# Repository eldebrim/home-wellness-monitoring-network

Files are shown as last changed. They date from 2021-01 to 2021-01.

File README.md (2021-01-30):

# Home Wellness Monitoring Network
 
## Overview
Develop a network of identical devices that keep track of positive activities through a usable interface.
Examples of activities to be tracked include taking medication, performing
exercise, and eating healthy food. The activities will be viewable through an online portal.
The portal will allow users to create custom activities so they can be tracked.

Each directory in this repo is used to store documentation for different blocks, along with the
files necessary to replicate them. A PDF setup guide is also included to explain how each device
is setup after it's manufactured.

Link to the team's Google site: https://sites.google.com/oregonstate.edu/ece44x201928/home-wellness-monitoring

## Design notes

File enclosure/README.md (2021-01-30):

# Enclosure
This directory includes the STL files used for the enclosure and lid. If you're an OSU student,
you can make use of the valley library (https://guides.library.oregonstate.edu/3Dprinting) to upload the
STL files and print the enclosure in 1-3 days.

Another alternative for 3D printing if you're not an OSU student is Print a Thing (https://printathing.com/).

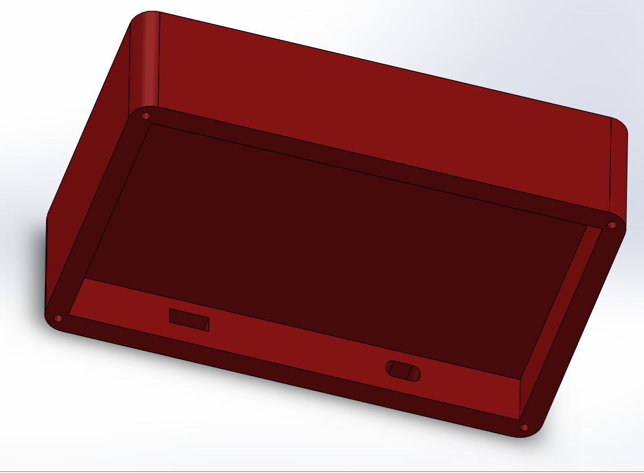
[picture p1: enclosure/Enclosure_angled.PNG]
Enclosure angled Enclosure Angled

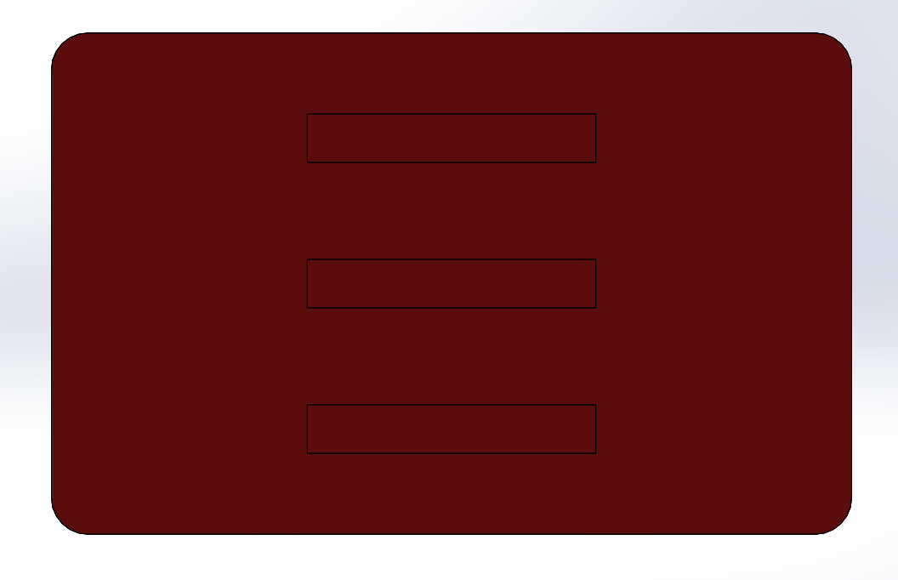
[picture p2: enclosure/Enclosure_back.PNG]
Enclosure back Enclosure Back

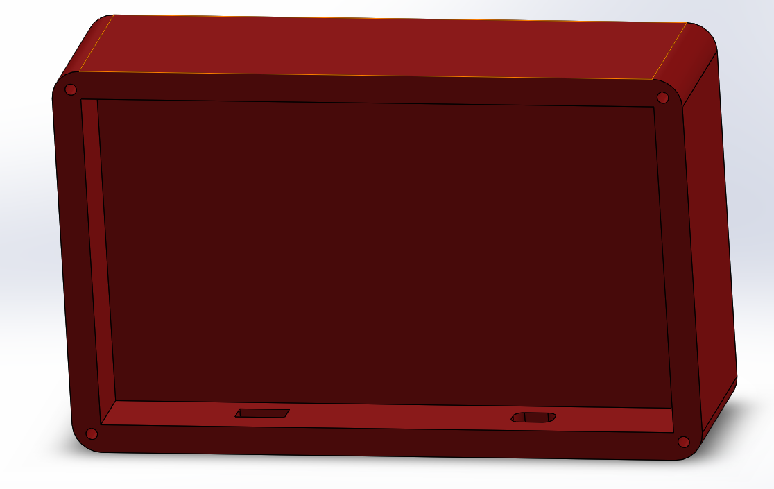
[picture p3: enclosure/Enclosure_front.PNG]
Enclosure front Enclosure Front

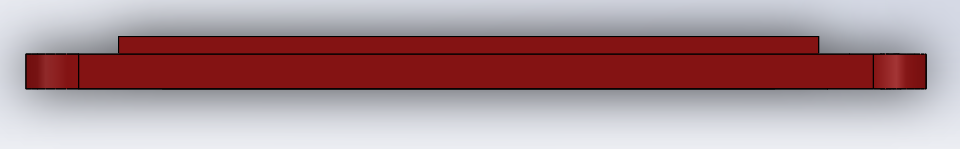
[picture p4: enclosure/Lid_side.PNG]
Lid side Lid Side

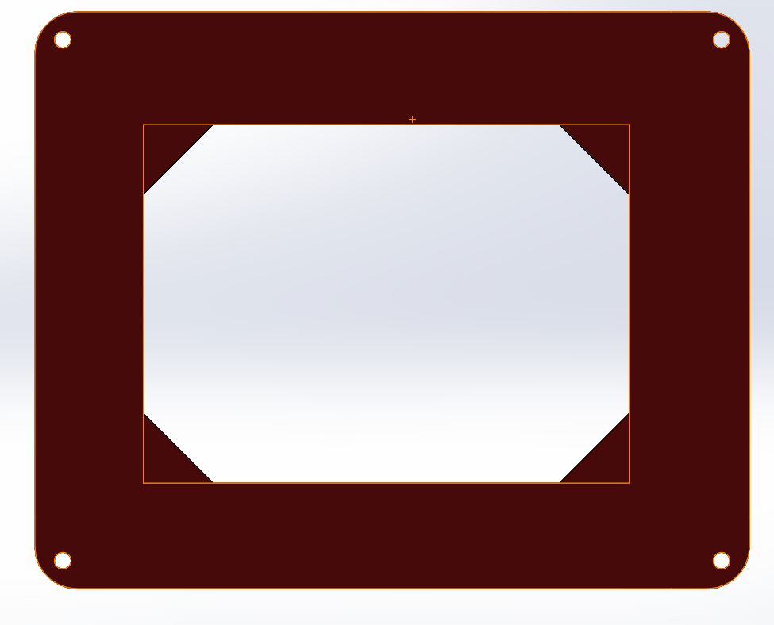
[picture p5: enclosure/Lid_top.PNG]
Lid top Lid Top


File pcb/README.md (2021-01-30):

# PCB
## Building PCB:
1. Go to OSH Park website (https://oshpark.com/).
2. Upload 'Board_1' from PCB Repository to the oshpark website by clicking the 'Browse For Files'.
3. Wait for OSH park to process files.
4. in 'Description' section enter 'Home Wellness Monitoring Network IOT Device.'
5. In 'Email' section enter your email.
6. click 'Continue' to go to 'Verify your design section'.
7. Click on 'Order' to place go to checkout section.
8. Enter your shipping and billing order to place an order for the PCB.

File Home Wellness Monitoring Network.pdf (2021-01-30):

User Guide

# Home Wellness Monitoring Network

Version 1.0

Introduction | 2
Monitoring Device Set-Up | 2
Connecting to Wi-Fi | 2
Wi-Fi troubleshooting | 3
Further Set-Up | 3
Web Profile Set-Up | 3

# Introduction

Welcome to your new Home Wellness Monitoring Network. We hope to help you with your wellness needs. Whether you want to remember to take your vitamins or brush your teeth, we hope this device can help you.

# Monitoring Device Set-Up

Out of the box, your Monitoring Device should have pre-installed magnets on the back, shown in Figure 1. After mounting it using these magnets, the Monitoring Device should be ready to plug into the wall. Plug it in and make sure the switch on the power cord is ON.

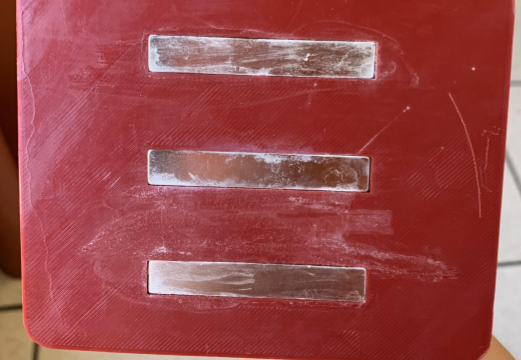
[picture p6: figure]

Figure 1. Three mounting magnets on backside of Monitoring Device

## Connecting to Wi-Fi

After turning on the Monitoring Device. You should be prompted to search for an access point for wireless connection. Simply select your wireless network from the list and enter the password if required.

Wi-Fi troubleshooting
If your wireless network is not listed, ensure your wireless router is in close proximity to the Monitoring Device.

## Further Set-Up

After connecting to a wireless network, your device should take a few moments to update to any settings that may be connected to that device’s identification number.

# Web Profile Set-Up

Proper utilization of the Home Wellness Monitoring Network requires set-up of the Web Profile.

1. Go to Website on a computer or smart device.
2. Create a secure account if you do not have one already
3. Add a device using the identification number which can be found on the backside of the device, as well as on the inside cover of the box the device originally was packaged in.
4. It is recommended that you name your device to ensure ease of use.
5. Add tasks under the device’s profile, as seen in Figure 2. Your device should automatically update, however, if the Monitoring Device does not self-refresh, reset the device by switching it off for five seconds and then switching it on again.

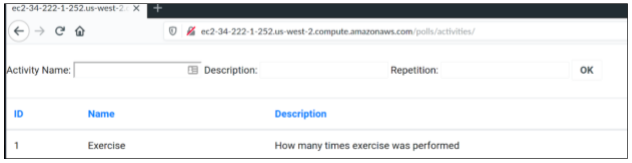
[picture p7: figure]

Figure 2. Adding a task to your device

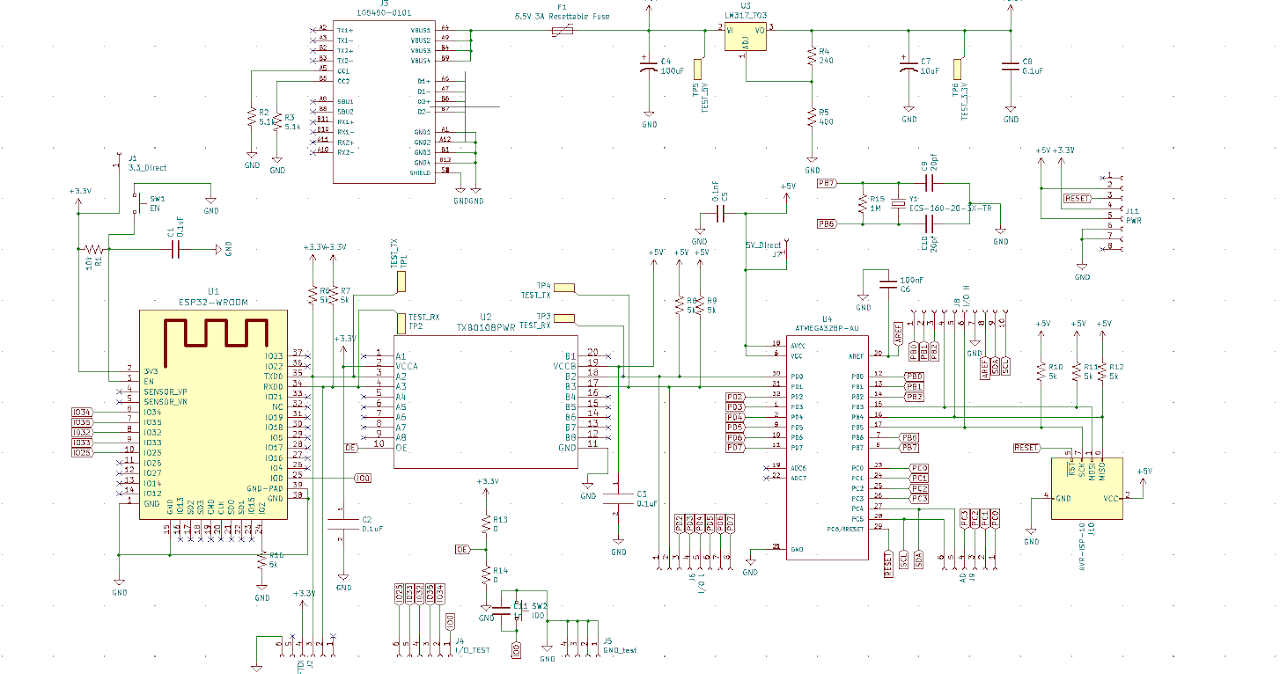
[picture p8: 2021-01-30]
pcb/pcb-schematic.png

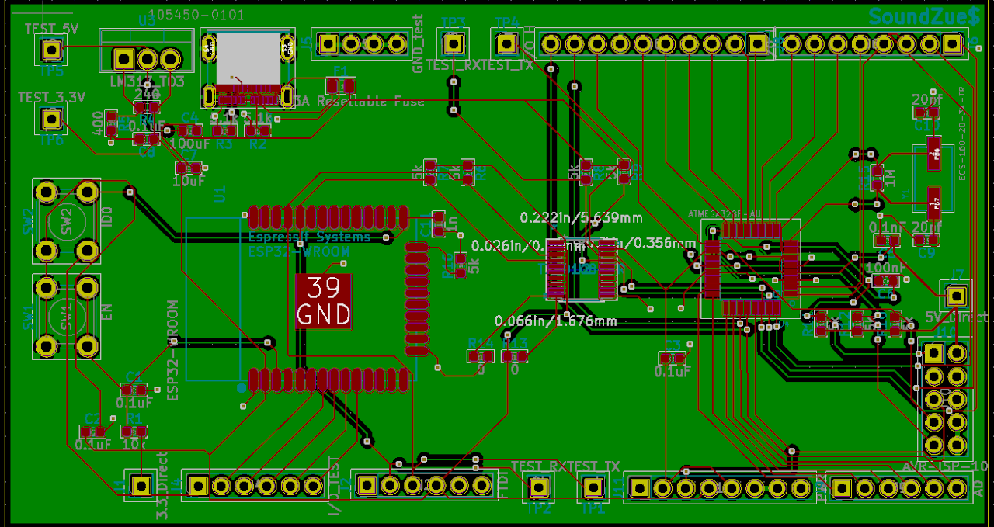
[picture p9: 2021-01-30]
pcb/pcb-board-layout.png

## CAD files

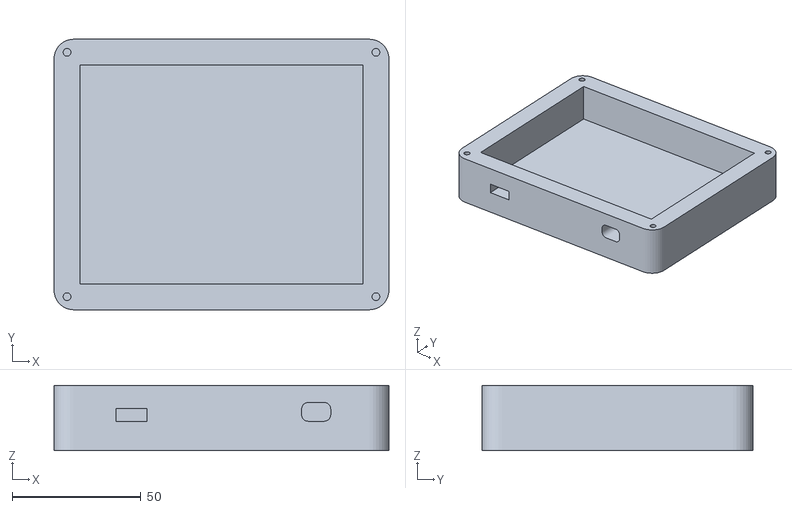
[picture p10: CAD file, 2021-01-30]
enclosure/Enclosure.STL
130.0 x 105.0 x 25.4

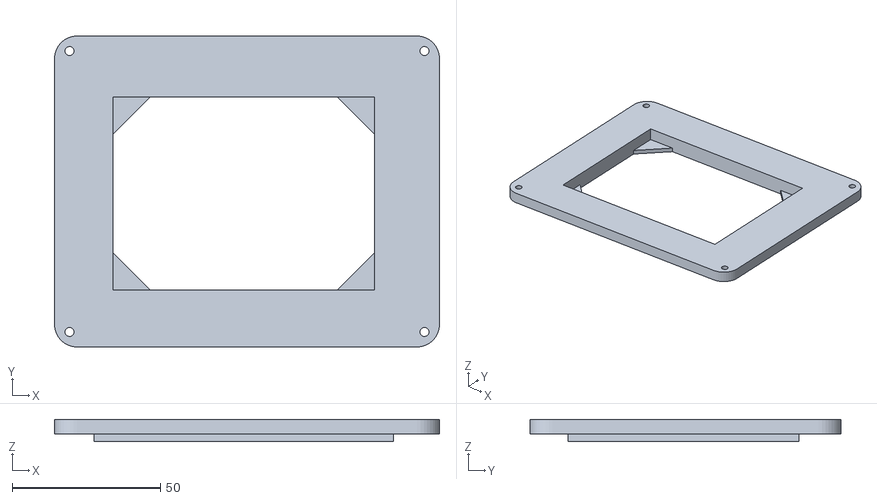
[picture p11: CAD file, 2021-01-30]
enclosure/Enclosure_Lid2.STL
130.0 x 105.0 x 7.54

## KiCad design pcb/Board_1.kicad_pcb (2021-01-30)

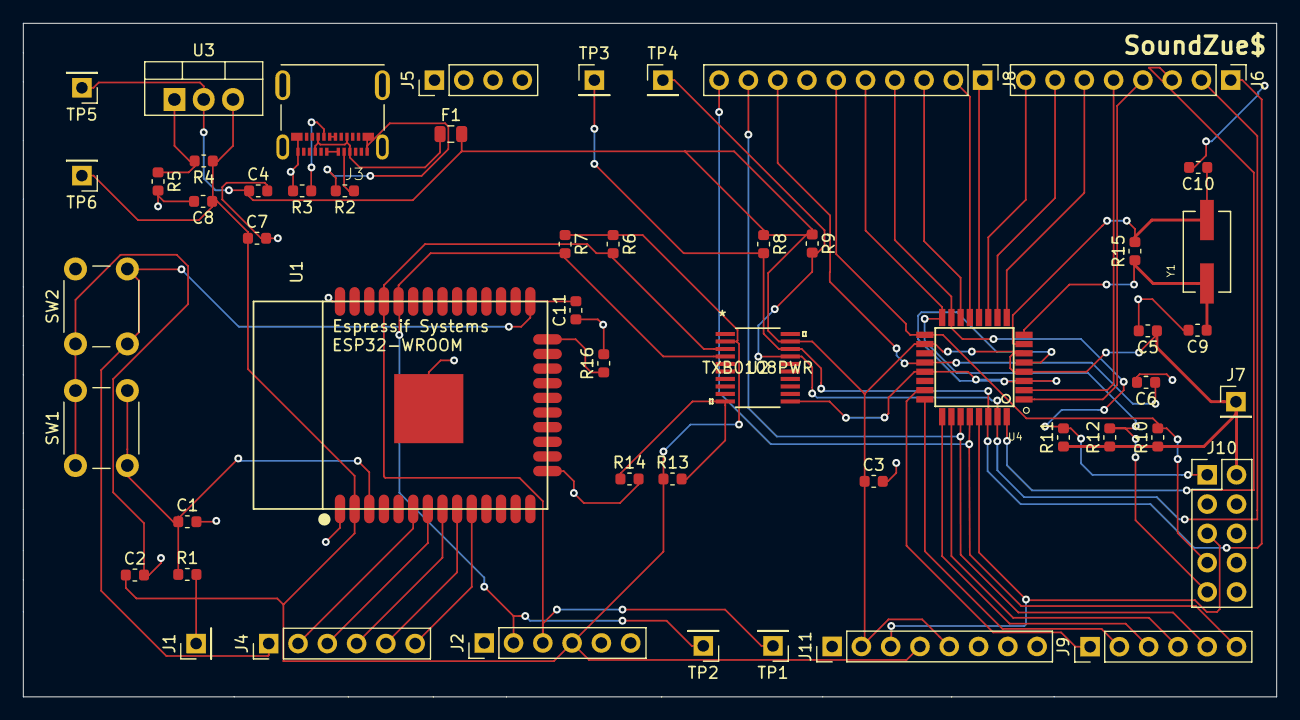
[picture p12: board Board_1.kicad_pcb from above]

Board: 2 copper layers, 108.7 x 58.4 mm, 52 parts (0 on the bottom side), 44 nets.

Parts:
C1, C2, C3, C8: 0.1uF; C_0603_1608Metric
C4: 100uF; C_0603_1608Metric
C5: 0.1nF; C_0603_1608Metric
C6: 100nF; C_0603_1608Metric
C7: 10uF; C_0603_1608Metric
C9, C10: 20pf; C_0603_1608Metric
C11: 1n; C_0603_1608Metric
F1: 5.5V 3A Resettable Fuse; Fuse_0805_2012Metric
J1: 3.3_Direct; PinHeader_1x01_P2.54mm_Vertical
J2: FTDI; PinHeader_1x06_P2.54mm_Vertical
J3: 105450-0101; MOLEX_105450-0101
J4: I/O_TEST; PinHeader_1x06_P2.54mm_Vertical
J5: GND_test; PinHeader_1x04_P2.54mm_Vertical
J6: I/0 L; PinHeader_1x08_P2.54mm_Vertical
J7: 5V_Direct; PinHeader_1x01_P2.54mm_Vertical
J8: I/O H; PinHeader_1x10_P2.54mm_Vertical
J9: AD; PinHeader_1x06_P2.54mm_Vertical
J10: AVR-ISP-10; PinHeader_2x05_P2.54mm_Vertical
J11: PWR; PinHeader_1x08_P2.54mm_Vertical
R1: 10k; R_0603_1608Metric
R2, R3: 5.1k; R_0603_1608Metric
R4: 240; R_0603_1608Metric
R5: 400; R_0603_1608Metric
R6, R7, R8, R9, R10, R11, R12, R16: 5k; R_0603_1608Metric
R13, R14: 0; R_0603_1608Metric
R15: 1M; R_0603_1608Metric
SW1: EN; SW_PUSH_6mm
SW2: ID0; SW_PUSH_6mm
TP1, TP4: TEST_TX; PinHeader_1x01_P2.54mm_Vertical
TP2, TP3: TEST_RX; PinHeader_1x01_P2.54mm_Vertical
TP5: TEST_5V; PinHeader_1x01_P2.54mm_Vertical
TP6: TEST_3.3V; PinHeader_1x01_P2.54mm_Vertical
U1: ESP32-WROOM
U2: TXB0108PWR
U3: LM317_TO3; TO-220-3_Vertical
U4: ATMEGA328P-AU; QFP80P900X900X120-32N
Y1: ECS-160-20-3X-TR; XTAL_ECS-160-20-3X-TR

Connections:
+3V3: C2.1, C7.1, C8.1, J1.1, J2.4, J11.4, R1.2, R4.1, R6.1, R7.1, R13.1, TP6.1, U1.2, U2.2, U3.3
+5V: C3.1, C4.1, C5.1, F1.2, J7.1, J10.2, J11.2, J11.5, R8.1, R9.1, R10.1, R11.1, R12.1, TP5.1, U2.19, U3.2, U4.4, U4.6, U4.18
AREF: C6.1, J8.8, U4.20
GND: C1.2, C2.2, C3.2, C4.2, C5.2, C6.2, C7.2, C8.2, C9.2, C10.2, C11.1, J2.6, J3.A1, J3.A12, J3.B1, J3.B12, J3.S1, J3.S2, J3.S3, J3.S4, J5.1, J5.2, J5.3, J5.4, J8.7, J10.4, J10.6, J10.8, J10.10, J11.6, J11.7, R2.2, R3.2, R5.2, R14.2, R16.2, SW1.1, SW2.1, U1.1, U1.15, U1.38, U1.39, U2.11, U4.3, U4.5, U4.21
I032: J4.4, U1.8
I033: J4.5, U1.9
IO0: C11.2, J4.1, SW2.2, U1.25
IO25: J4.6, U1.10
IO34: J4.2, U1.6
IO35: J4.3, U1.7
unnamed: C1.1, R1.1, SW1.2, U1.3
unnamed: F1.1, J3.A4, J3.A9, J3.B4, J3.B9
unnamed: J2.2, R7.2, TP2.1, U1.34, U2.4
unnamed: J2.3, R6.2, TP1.1, U1.35, U2.3
unnamed: J3.A5, R2.1
unnamed: J3.A6, J3.A7
unnamed: J3.B5, R3.1
unnamed: J3.B6, J3.B7
unnamed: J6.1, R8.2, TP3.1, U2.18, U4.30
unnamed: J6.2, R9.2, TP4.1, U2.17, U4.31
unnamed: J8.4, J10.1, R11.2, U4.15
unnamed: J8.6, J10.7, R10.2, U4.17
unnamed: J8.5, J10.9, R12.2, U4.16
unnamed: R4.2, R5.1, U3.1
unnamed: R16.1, U1.24
OE: R13.2, R14.1, U2.10
PB0: J8.1, U4.12
PB1: J8.2, U4.13
PB2: J8.3, U4.14
PB6: C10.1, R15.2, U4.7, Y1.2
PB7: C9.1, R15.1, U4.8, Y1.1
PC0: J9.1, U4.23
PC1: J9.2, U4.24
PC2: J9.3, U4.25
PC3: J9.4, U4.26
PD2: J6.3, U4.32
PD3: J6.4, U4.1
PD4: J6.5, U4.2
PD5: J6.6, U4.9
PD6: J6.7, U4.10
PD7: J6.8, U4.11
RESET: J10.5, J11.3, U4.29
SCL: J8.10, J9.6, U4.28
SDA: J8.9, J9.5, U4.27

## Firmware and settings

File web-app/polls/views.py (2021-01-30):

from django.shortcuts import render
from django.http import HttpResponse
from .models import Activity
from django.http.response import JsonResponse
from django.views.decorators.csrf import csrf_exempt
from django.core import serializers
from basicauth.decorators import basic_auth_required
import time


# Create your views here.
def index(request):
    return HttpResponse("Hh")

def detail(request, question_id):
    return HttpResponse("You're looking at question %s." % question_id)

def results(request, question_id):
    response = "You're looking at the results of question %s."
    return HttpResponse(response % question_id)

def vote(request, question_id):
    return HttpResponse("You're voting on question %s." % question_id)

@csrf_exempt
def add(request):
    if request.method == 'POST':
#        print(request.body)
        return HttpResponse("Website recieved activity: " + str(request.body))

def list(request):
    #if request.method == 'GET':
    serialized_queryset = serializers.serialize('python', Activity.objects.all())
#    print(serialized_queryset)
    return JsonResponse(serialized_queryset, safe=False)

@csrf_exempt
@basic_auth_required
def activities(request):
    if request.method == 'POST':
        activity_name = request.POST.get("activity_name","")
        activity_description = request.POST.get("activity_description","")
        activity_repetition = request.POST.get("repetition","")
        start = time.time()
        b1 = Activity(name=activity_name, description=activity_description, repetition=activity_repetition)
        b1.save()
        end = time.time()
        print("Time taken to store single object: ", end - start, " seconds")

    istekler = Activity.objects.all()
    
    start = time.time()
    render(request, 'list.html', locals())
    end = time.time()
    print("Time taken to render: ", end - start, " seconds")

    start = time.time()
    test_activity = Activity.objects.get(pk=1)
    end = time.time()
    print("Single object from database: Name: " + test_activity.name + ", Description: " + test_activity.description)
    print("Time taken to get single object from database: ", end - start, " seconds")

    return render(request, 'list.html', locals())

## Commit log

2021-01-30 Add STL files and initial enclosure documentation
    [Alex_Thompson_Enclosure.STL, Alex_Thompson_Enclosure_Lid2.STL]
2021-01-30 Add more documentation and PCB pictures
2021-01-30 Fix enclosure filenames
    [Enclosure.STL, Enclosure_Lid2.STL]
2021-01-30 Add enclosure model images and show them in the README

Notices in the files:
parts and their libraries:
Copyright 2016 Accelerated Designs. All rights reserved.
